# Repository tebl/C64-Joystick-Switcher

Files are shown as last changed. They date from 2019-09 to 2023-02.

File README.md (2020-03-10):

# C64 Joystick Switcher
I was watching [MsMadLemon](https://www.youtube.com/channel/UCSlMemxuBOFu6Rz_Al02nHQ) on [Youtube](https://youtu.be/DOF_CZoSF5g) the other day and she was making an autofire circuit, so naturally I wanted to build one too! Starting with the [C64 Mega Switcher](https://github.com/tebl/C64-Mega-Switcher) for the Commodore 64 (when you want to use Sega Genesis or Mega Drive Controllers instead), I stripped away some parts to clear space for the autofire parts, redesigned it a couple of times and then finally sketched out the whole thing again in order to figure out all the ways it didn't work. The last one thankfully worked, so now it's open and available for anyone with fingers they are willing to risk burning with a soldering iron (don't do that by the way, it hurts)!

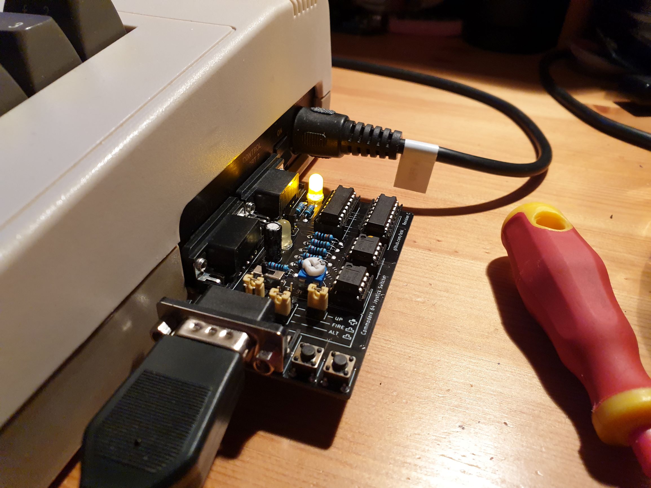
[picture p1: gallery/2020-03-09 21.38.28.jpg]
C64 Joystick Switcher


## Building the switcher
Soldering together the few components should be easy going as long as you have access to reasonable tools, personally I'm using a cheap soldering station with adjustable temperature so no need to go expensive if you don't have to. Use 60/40 soldering tin of reasonable quality, but stay away from the lead-free stuff unless you have experience working with it.

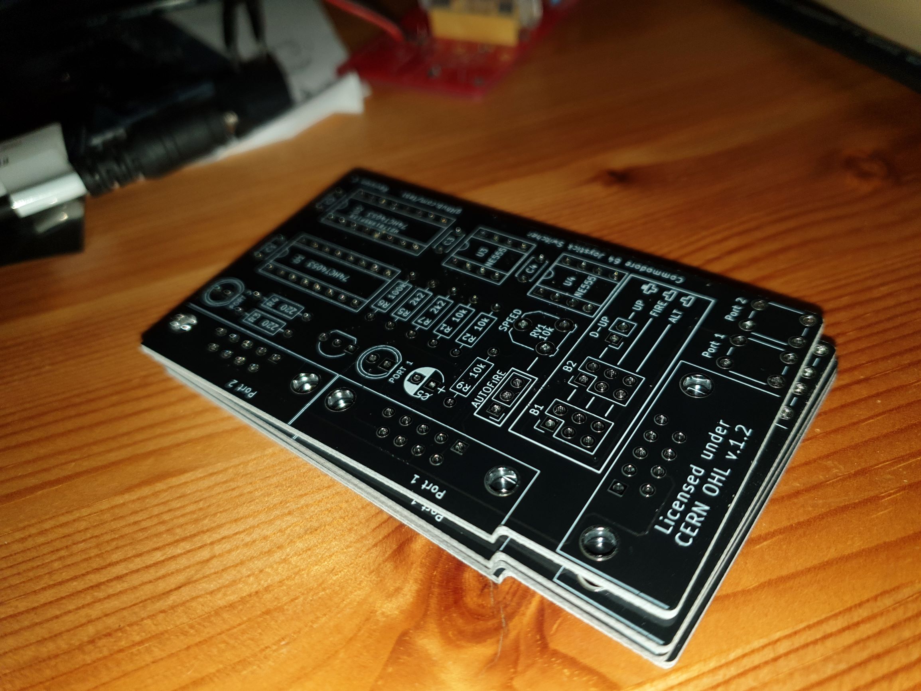
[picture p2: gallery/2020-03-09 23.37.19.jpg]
Bare PCB


Start by studying the PCB, both sides and perform dry fits to see that you have an idea of where everything goes since removing things is always a lot harder than getting it right in the first place (match orientation to symbols, see gallery images for reference if you're unsure). The diodes are installed standing, the stripe goes into the board so that it is laying directly against the board - a hint for making these look pretty, is wrapping one of the wires around a small screwdriver to get the loops looking almost identical!

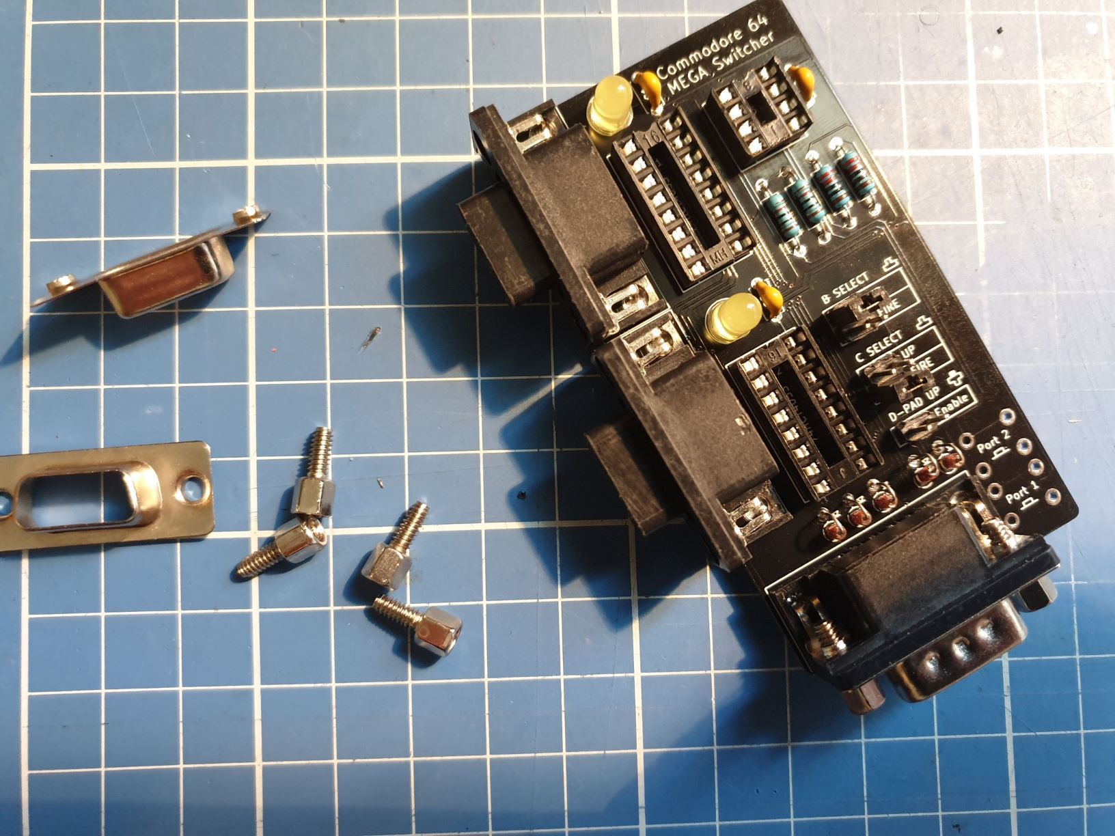
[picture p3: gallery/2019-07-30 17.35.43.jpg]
DB9 connector


The female DB9 connectors used for port 1/2 comes with a metal shroud, this comes off when you remove the two screws that would be in the way anyway (see image above for reference). Given that the C64 ports are made out of plastic, the metal shroud is not needed though you could possibly keep it by gluing it to the connector if you really wanted to, alternatively you could also fill the mounting holes with solder to keep them together afterwards. Do a testfit of the connectors with the C64 before soldering them to the board, this is recommended in order to avoid adding any stress to the C64 board.

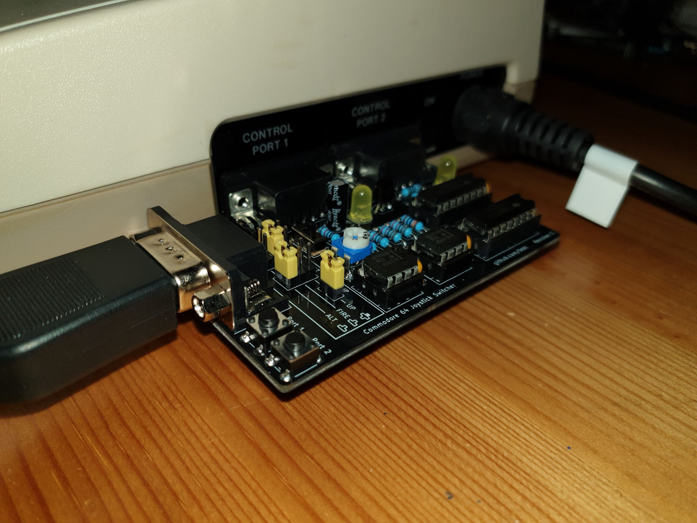
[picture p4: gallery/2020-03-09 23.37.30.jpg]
Connected to C64


Other than that, just take your time when doing the assembly - start by installing the smallest components first and then work your way up from there. Before actually plugging in anything into any antique computers, do a thorough visual inspection for any accidental solder-bridges. As a finishing note, I recommend putting something under the PCB to help support when pushing the buttons.

## Using the switcher
Firmly insert the switcher into the C64, making sure that it is inserted the whole way and fits firmly without feeling loose. When playing a game, if you encounter a game that expects a joystick inserted into the other port you can use the switches to change the currently active port.

**WARNING!**
 - Do **NOT** move any of the jumpers while the computer is switched on, doing so may cause damage to it. Always power off first!
 - Do **NOT** jumper so that more than one button/direction does the same thing, for example: if you jumper the B1 button for UP, then you have to REMOVE the jumper enabling D-PAD UP!
 - Do **NOT** use with actual Sega Genesis or Mega Drive controllers, if you want to use one of those - use [C64 Mega Switcher](https://github.com/tebl/C64-Mega-Switcher) instead.

You can use any common Atari-style joystick such as the Competition Pro and Zipstick, they are the ones I've tested with and currently also have in my collection. You can use the secondary fire button if you have one wired with this capability, most commonly the pinout is compatible with the Sega Master System gamepad. An auto-fire circuit has been added to the module, this can be handy if your controller does not include this functionality. 

# Schematic
The supplied KiCad files should be sufficient as both a schematic and as a  starting point for ordering PCBs (basically you could just zip the contents of the export folder and upload that on a fabrication site), the schematic is also available in [PDF-format](https://github.com/tebl/C64-Joystick-Switcher/raw/master/export/C64%20Joystick%20Switcher.pdf) and this is what you'll need to print and work your way through this things don't work as expected after assembly.

# BOM
Most parts should be easy to get a hold of from your favourite local electronic component shop, but given that I don't have access to such shops where I live so everything was based on whatever I could get cheapest from ebay/AliExpress (free shipping most places, but plan on waiting 3-4 weeks though). Pin headers are bought as strips with 40 pins, single or double rows, that you break into the specified sizes. Any amounts given in paranthesis are for optional functionality, mainly autofire and capability to utilize the secondary fire button if you have one. 

| Reference | Item | Count |
| --- | --- | ----- |
| PCB | Fabricate using Gerber files ([order](https://www.pcbway.com/project/shareproject/Commodore_64_Joystick_Switcher__Revision_C_.html?inviteid=88707)) | 1 |
| C1-C4 | 100nF capacitor | 4 |
| C5 | 10uF electrolytic capacitor | (1)|
| D1,D2 | 5mm LED | 2 |
| J1,J2 | Female DB9 right-angle connector | 2 |
| J3 | Male DB9 right-angle connector | 1 |
| J4,J5 | 2x3-pin straight header | 2 |
| JP2 | 3-pin straight header | 1 |
| Q1 | BC547 transistor (TO-92) | (1)|
| R1,R2 | 10k ohm resistor | 2 | 
| R3,R4 | 220 ohm resistor | 2 |
| R5,R7 | 2k2 (2200) ohm resistor | (2)|
| R6 | 100k ohm resistor | (1)|
| R9 | 10k ohm resistor | (1)| 
| RV1 | 10k ohm potentiometer (RM-065) | (1)| 
| U1,U2 | 74HCT4053 or CD4053 (DIP-16) | 2 |
| U3 | NE555 (DIP-8) | 1 |
| U4 | NE555 (DIP-8) | (1)|
| SW1,SW2 | SPST momentary push button | 2 |

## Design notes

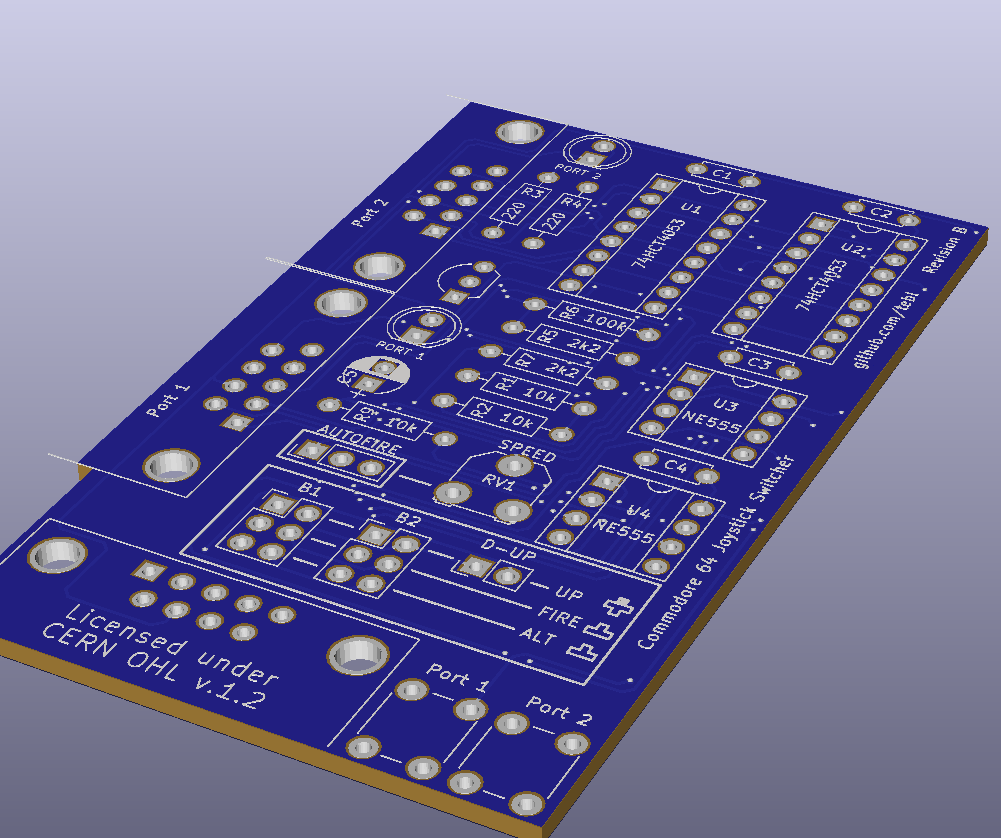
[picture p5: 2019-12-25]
gallery/C64 Joystick Switcher #2.png

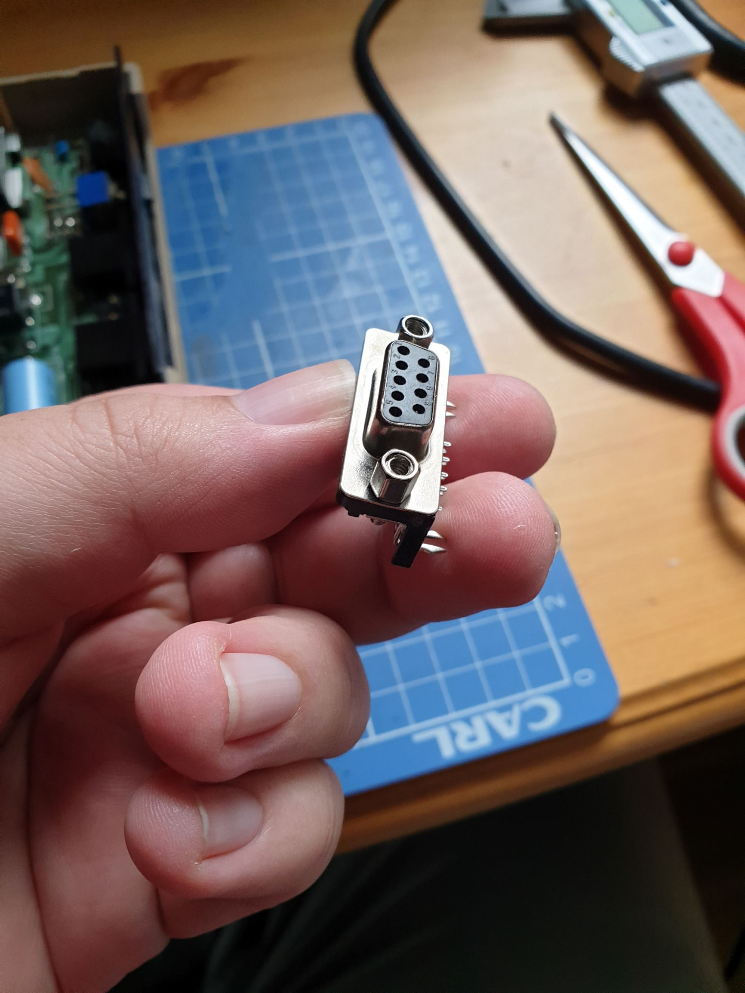
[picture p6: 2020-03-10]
gallery/2019-06-24 13.09.16.jpg

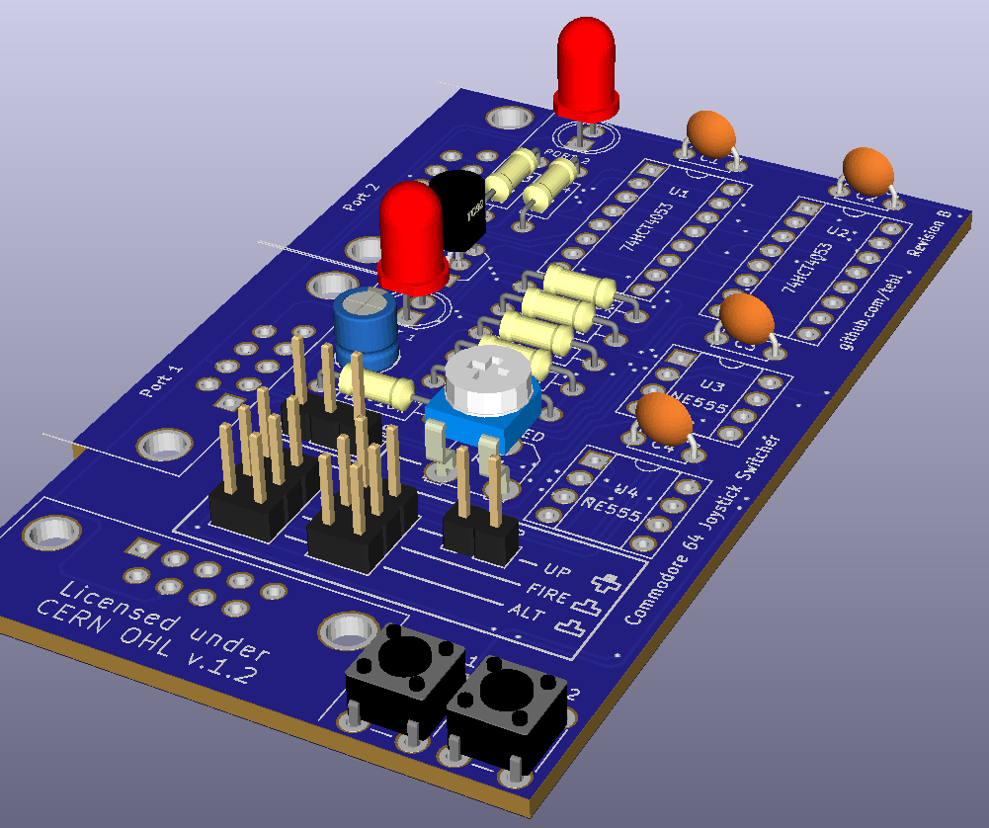
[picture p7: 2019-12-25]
gallery/C64 Joystick Switcher #1.png

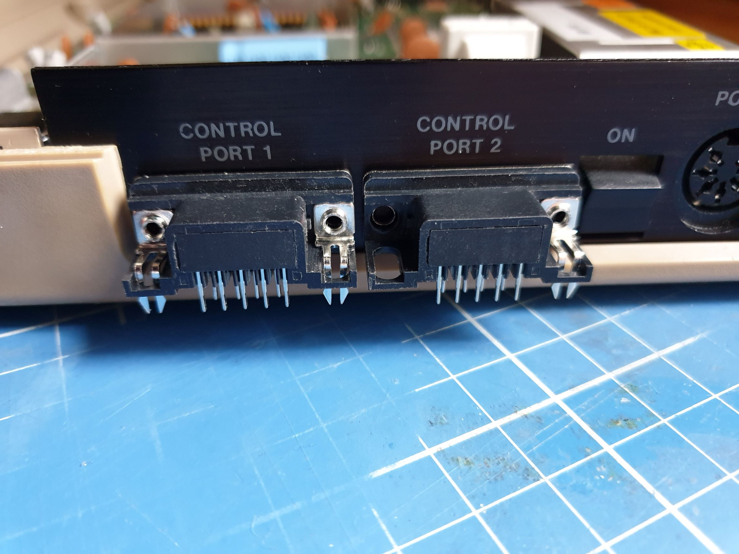
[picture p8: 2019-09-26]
gallery/2019-06-24 13.32.10.jpg

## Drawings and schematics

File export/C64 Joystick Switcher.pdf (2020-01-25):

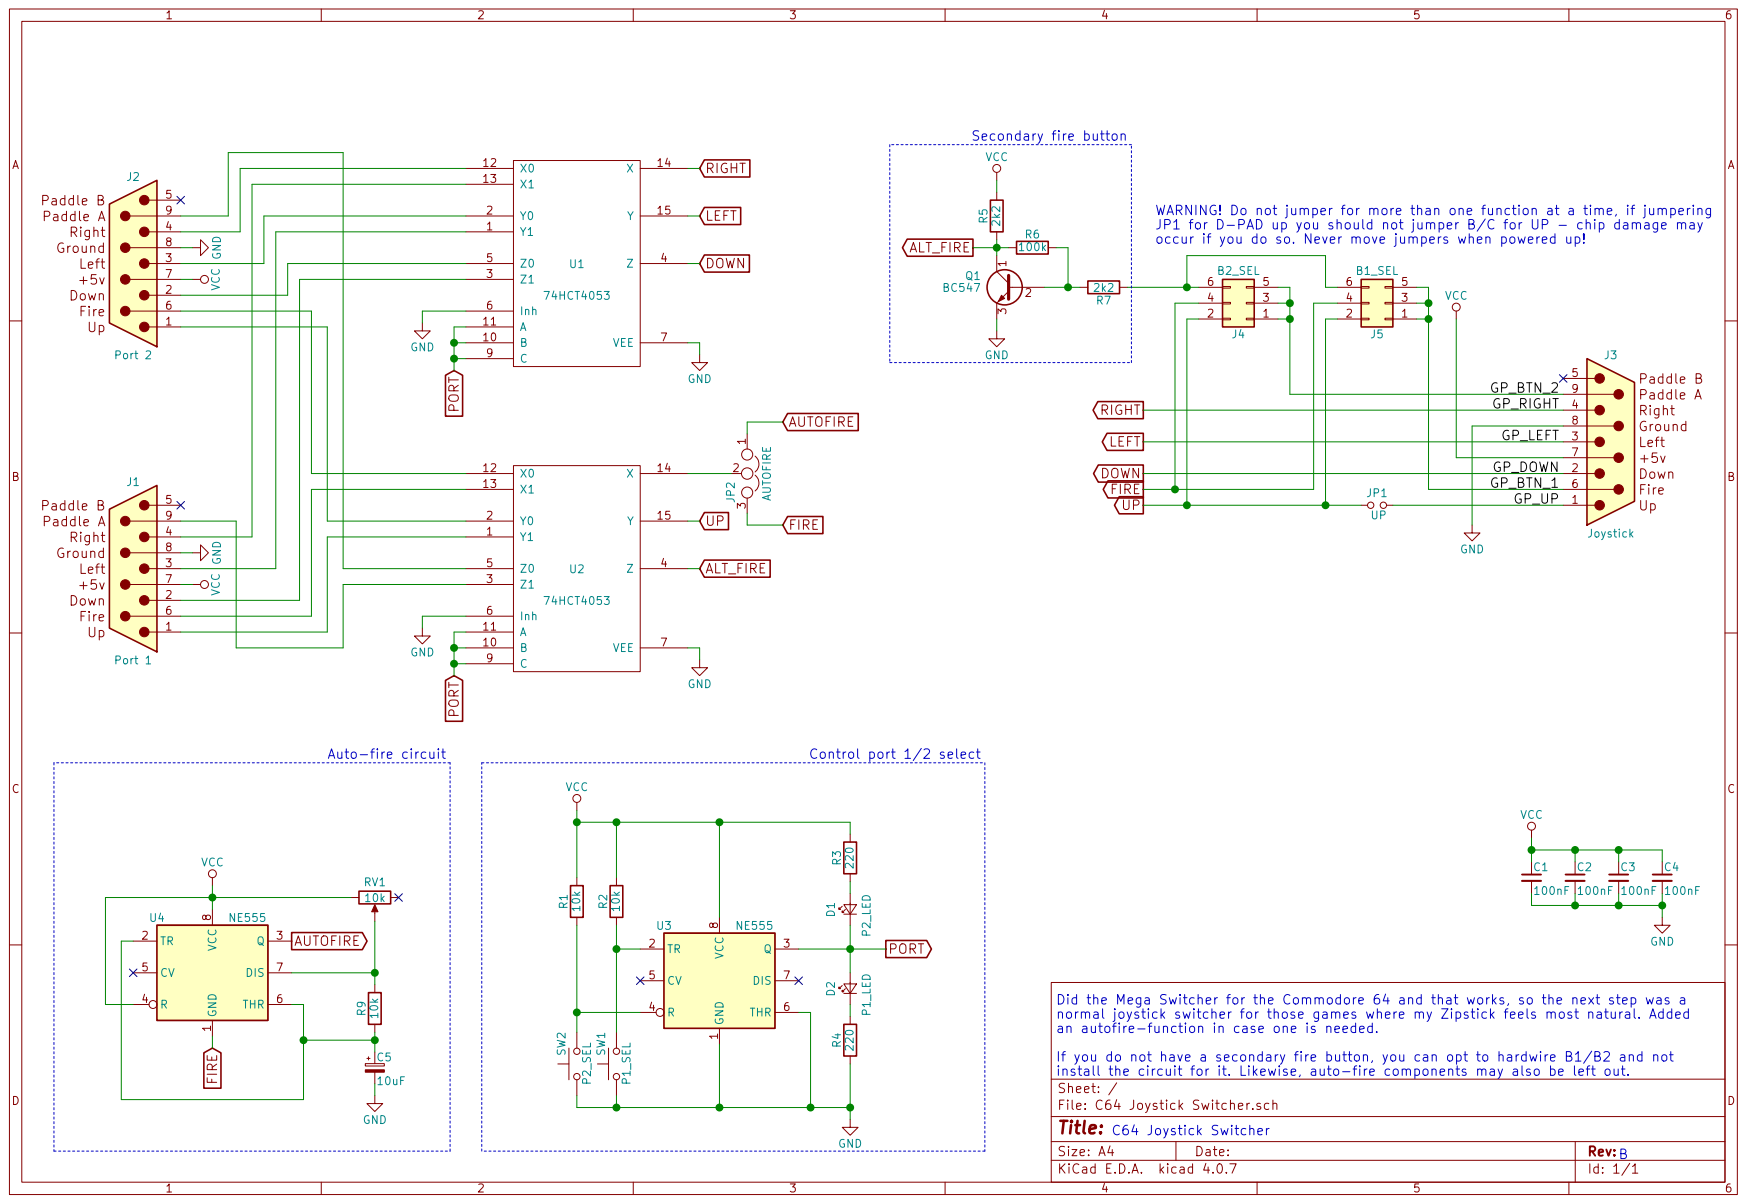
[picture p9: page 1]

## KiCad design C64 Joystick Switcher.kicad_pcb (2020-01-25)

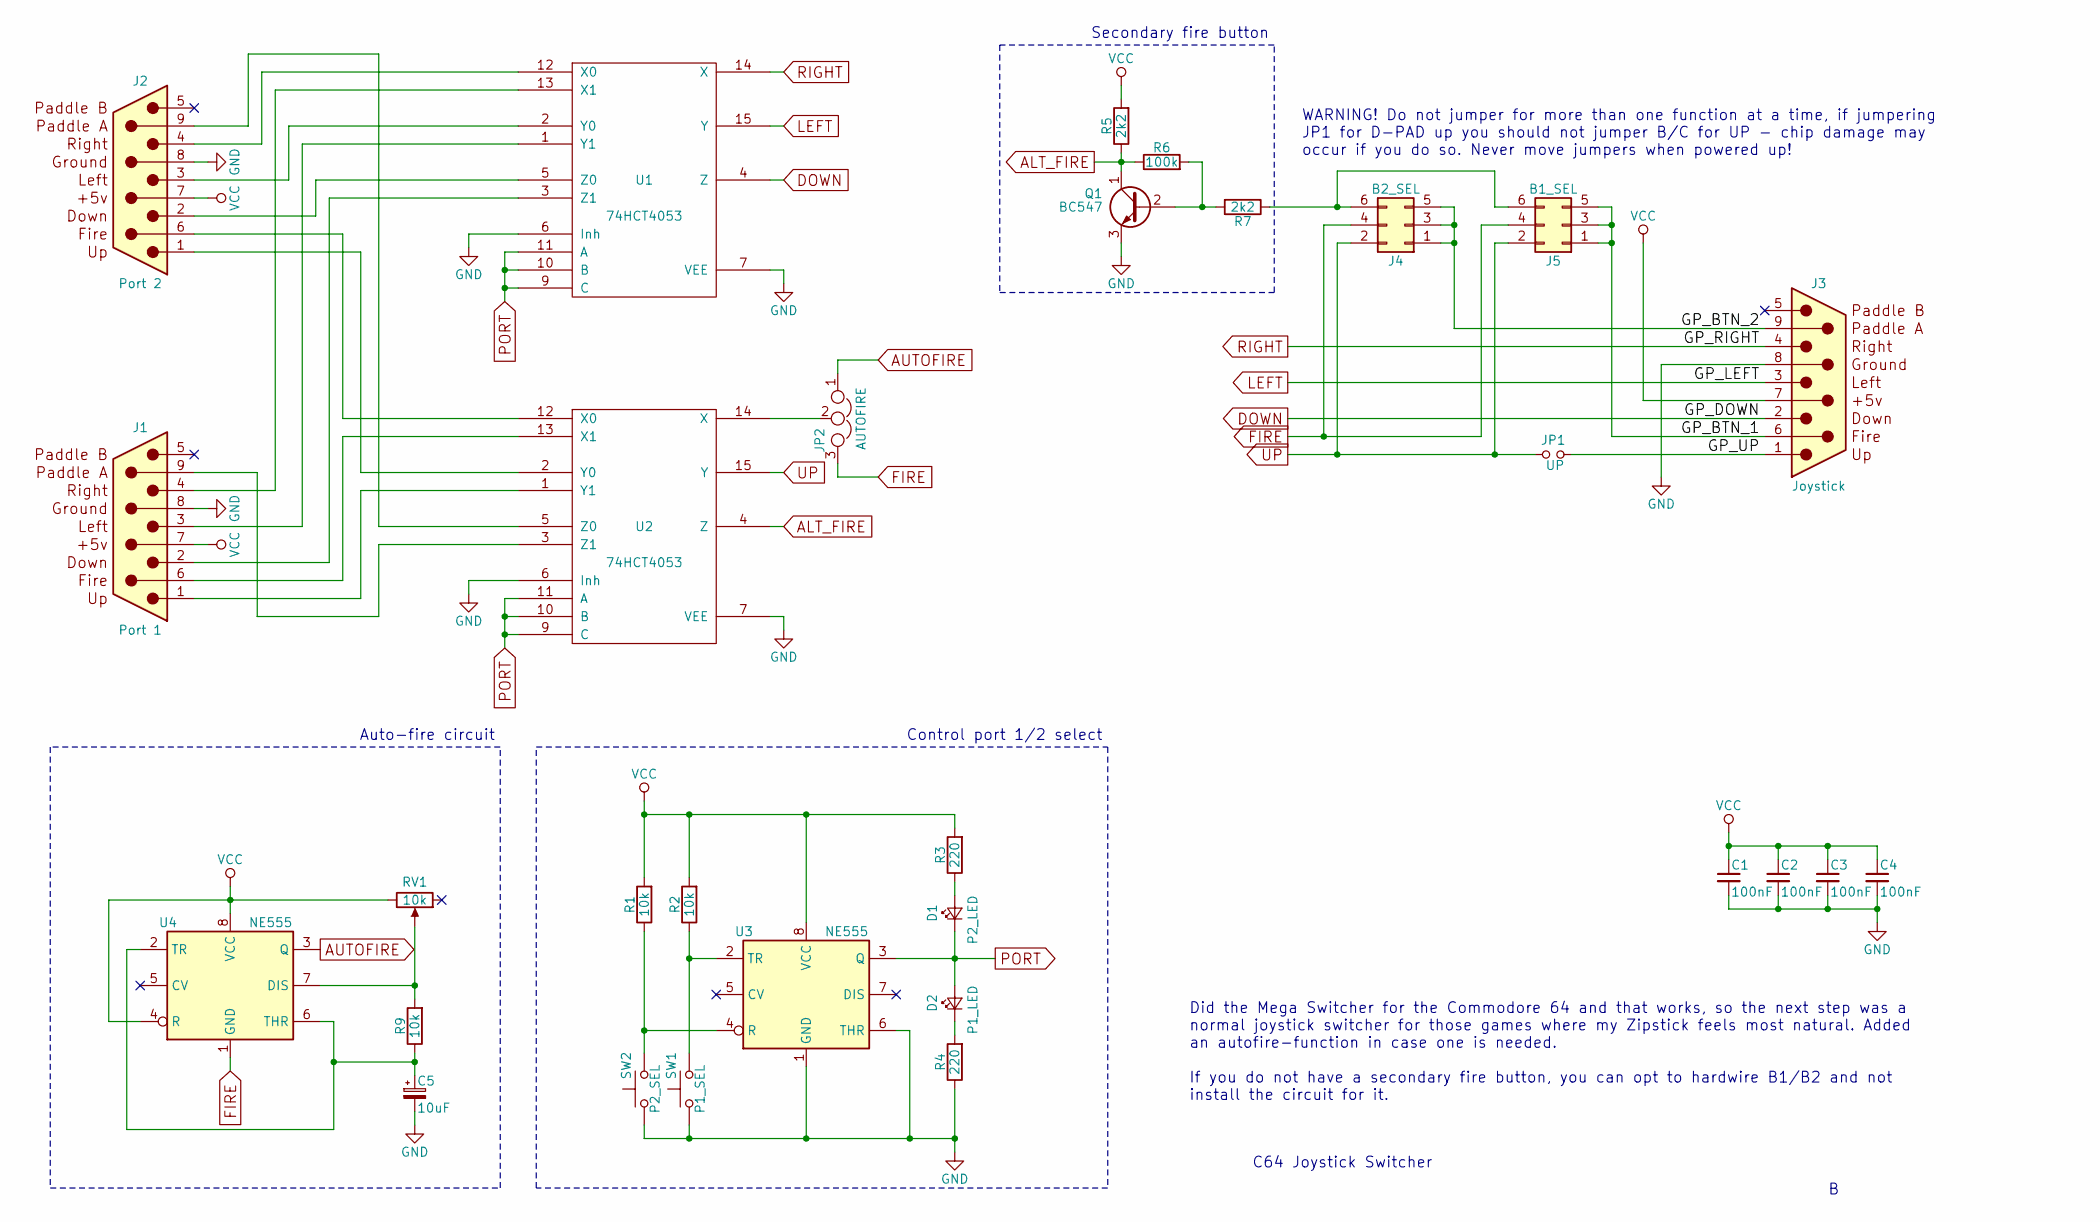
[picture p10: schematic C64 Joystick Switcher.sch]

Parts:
C1, C2, C3, C4: 100nF; C_Disc_D4.7mm_W2.5mm_P5.00mm
C5: 10uF; CP_Radial_D5.0mm_P2.50mm
D1: P2_LED; LED_D5.0mm
D2: P1_LED; LED_D5.0mm
J1: Port 1; DSUB-9_Female_Horizontal_P2.77x2.84mm_EdgePinOffset7.70mm_H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
J2: Port 2; DSUB-9_Female_Horizontal_P2.77x2.84mm_EdgePinOffset7.70mm_H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
J3: Joystick; DSUB-9_Male_Horizontal_P2.77x2.84mm_EdgePinOffset7.70mm_Hou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
J4: B2_SEL; Pin_Header_Straight_2x03_Pitch2.54mm
J5: B1_SEL; Pin_Header_Straight_2x03_Pitch2.54mm
JP1: UP; Pin_Header_Straight_1x02_Pitch2.54mm
JP2: AUTOFIRE; Pin_Header_Straight_1x03_Pitch2.54mm
Q1: BC547; TO-92_Inline_Wide
R1, R2, R9: 10k; R_Axial_DIN0207_L6.3mm_D2.5mm_P10.16mm_Horizontal
R3, R4: 220; R_Axial_DIN0207_L6.3mm_D2.5mm_P10.16mm_Horizontal
R5, R7: 2k2; R_Axial_DIN0207_L6.3mm_D2.5mm_P10.16mm_Horizontal
R6: 100k; R_Axial_DIN0207_L6.3mm_D2.5mm_P10.16mm_Horizontal
RV1: 10k; Potentiometer_Triwood_RM-065
SW1: P1_SEL; SW_PUSH_6mm
SW2: P2_SEL; SW_PUSH_6mm
U1, U2: 74HCT4053; DIP-16_W7.62mm_Socket
U3, U4: NE555; DIP-8_W7.62mm_Socket

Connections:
/GP_BTN_1: J3.6, J5.1, J5.3, J5.5
/GP_BTN_2: J3.9, J4.1, J4.3, J4.5
/GP_UP: J3.1, JP1.2
ALT_FIRE: Q1.1 (C), R5.1, R6.1, U2.4 (Z)
AUTOFIRE: JP2.1, U4.3 (Q)
DOWN: J3.2, U1.4 (Z)
FIRE: J4.4, J5.4, JP2.3, U4.1 (GND)
GND: C1.2, C2.2, C3.2, C4.2, C5.2, J1.8 (GND), J2.8 (GND), J3.8 (GND), Q1.3 (E), R4.1, SW1.1, SW2.1, U1.6 (Inh), U1.7 (VEE), U1.8 (GND), U2.6 (Inh), U2.7 (VEE), U2.8 (GND), U3.1 (GND), U3.6 (THR)
LEFT: J3.3, U1.15 (Y)
unnamed: C5.1, R9.1, U4.2 (TR), U4.6 (THR)
unnamed: D1.2 (A), R3.1
unnamed: D2.1 (K), R4.2
unnamed: J1.1, U2.1 (Y1)
unnamed: J1.2, U1.3 (Z1)
unnamed: J1.3, U1.1 (Y1)
unnamed: J1.4, U1.13 (X1)
unnamed: J1.6, U2.13 (X1)
unnamed: J1.9, U2.3 (Z1)
unnamed: J2.1, U2.2 (Y0)
unnamed: J2.2, U1.5 (Z0)
unnamed: J2.3, U1.2 (Y0)
unnamed: J2.4, U1.12 (X0)
unnamed: J2.6, U2.12 (X0)
unnamed: J2.9, U2.5 (Z0)
unnamed: J4.6, J5.6, R7.1
unnamed: JP2.2, U2.14 (X)
unnamed: Q1.2 (B), R6.2, R7.2
unnamed: R1.1, SW2.2, U3.4 (R)
unnamed: R2.1, SW1.2, U3.2 (TR)
unnamed: R9.2, RV1.2, U4.7 (DIS)
PORT: D1.1 (K), D2.2 (A), U1.9 (C), U1.10 (B), U1.11 (A), U2.9 (C), U2.10 (B), U2.11 (A), U3.3 (Q)
RIGHT: J3.4, U1.14 (X)
UP: J4.2, J5.2, JP1.1, U2.15 (Y)
VCC: C1.1, C2.1, C3.1, C4.1, J1.7 (VCC), J2.7 (VCC), J3.7 (VCC), R1.2, R2.2, R3.2, R5.2, RV1.3, U1.16 (VCC), U2.16 (VCC), U3.8 (VCC), U4.4 (R), U4.8 (VCC)

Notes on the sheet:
C64 Joystick Switcher
WARNING! Do not jumper for more than one function at a time, if jumpering JP1 for D-PAD up you should not jumper B/C for UP - chip damage may occur if you do so. Never move jumpers when powered up!
Did the Mega Switcher for the Commodore 64 and that works, so the next step was a normal joystick switcher for those games where my Zipstick feels most natural. Added an autofire-function in case one is needed. If you do not have a secondary fire button, you can opt to hardwire B1/B2 and not instal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
Auto-fire circuit
Control port 1/2 select
Secondary fire button

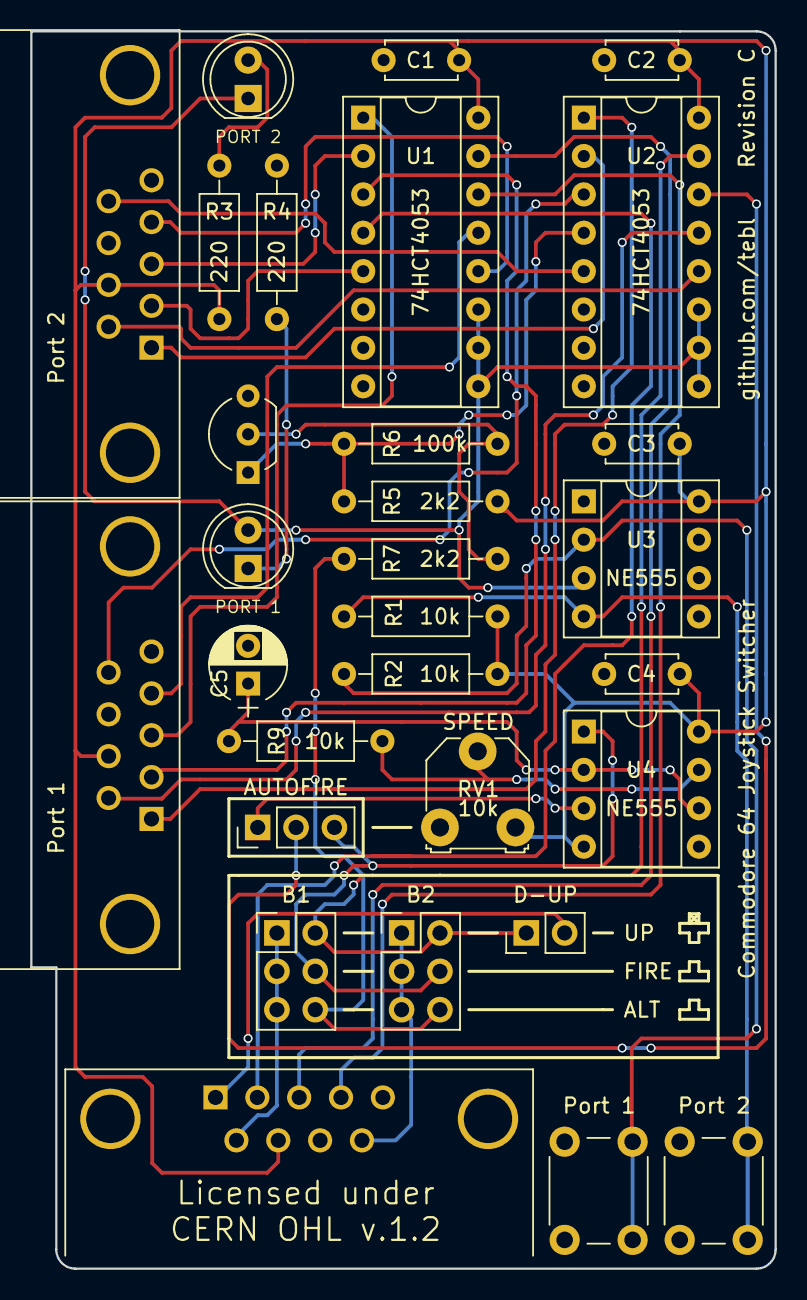
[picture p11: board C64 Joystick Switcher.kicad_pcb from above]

Board: 2 copper layers, 49.3 x 81.9 mm, 30 parts (0 on the bottom side), 34 nets.

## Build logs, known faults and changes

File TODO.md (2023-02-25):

# TODO
- Update project files to recent KiCAD
- Figure out a way to use port 1 fire button (SPACE on keyboard) when port 2 is selected.

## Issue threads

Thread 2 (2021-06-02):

Need Transistor?

NuClear235, 2021-06-02:
Hello,
Do I need transistor circuit, when I will use standard Atari Joystick with Button2 wired to pin9 of connector, please?
What function Transitor has? I dont want to use Sega controller anyway…
Thank You

tebl, 2021-06-03:
The C64 secondary button needs to be active high as it is connected to the
SiD chips analog input. The transistor as well as R5-R7 forms an inverter
for devices designed with an active low signal for this button (the most
common of these is the SMS gamepad).

When used with a C64GS controller that has already been wired correctly,
you can wire the circuit as expected by leaving out transistor as well as
R5-R7 - install wire links for R6 and R7.

Do however check the wiring on your joystick before doing so, the SID chip
don't like being shorted.

ons. 2. jun. 2021, 22:31 skrev NuClear235 ***@***.***>:

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

NuClear235, 2021-06-04:
Thank for answer.
I am using my own adapter, where is Button2 of Joy2 connected to Button1 of Joy1. So can have Fire2 button in games where is Button2 not supported, but is for action used SPACEBAR key.
Commando game throws grenades by SPACEBAR key. So I am using Button2 for it. This is  working only with selected joystick2 as main!
I will try improve  Your adapter to this function.
Best will be on B2SEL one more jumper possition /SPACEBAR/. Where will be signal connected to pin13.
Now I will just replace B2sel pin4 to harwired on fire13. I am just not sure what will do when will select main joystick 1 and press fire2 button with selected autofire. Will not be problem with grounding autofire out ?

NuClear235, 2021-06-07:
Hello,

Thank You for tips!

What do You mean on this message (see pic)?
What are jumpers B/C ?

Arent You on facebook or WhatsUp for just quick mesaging ?

Thank You

Michal Polak

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

tebl, 2021-06-07:
Jumpers B/C refer to the two 2x3 pin headers on the board, it is leftover
reference to an older similar project (uses Mega Drive/Genesis gamepads
instead). The are called B1_SEL and B2_SEL here, mainly allowing the
function of buttons to be swapped or have one work as up direction.

I rarely use the social platforms, for project discussion i prefer them on
github as the content may be of interest to other builders.

man. 7. jun. 2021, 07:54 skrev NuClear235 ***@***.***>:

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

NuClear235, 2021-06-07:
OK.

What could do, when I connecter Fire Button to UP without remove Jumper 1 ?

Isnt classic joystick just pasive switching signals to GND?

Michal

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

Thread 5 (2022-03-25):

Autofire not Working

fbugallo, 2022-03-25:
Hi, I can't get Auto Fire to work.

I am using PCBWAY revision C (https://www.pcbway.com/project/shareproject/Commodore_64_Joystick_Switcher__Revision_C_.html).

Assemble everything as indicated, and the other functionalities work perfectly.

I changed the 555 chip for a new one to see if it was the problem, I adjusted the preset and I didn't get any change at all, just no autofire.

What could it be? I can upload photos if you think necessary.

Thanks

fbugallo, 2022-03-26:
I changed the 555 for another brand and it worked fine. That same 555 worked ok for the port select function. I assume there is an incompatibility or it was a fake.

tebl, 2022-10-11:
Is JP2 set with pins 1-2 jumped? A broken RV1 would cause such an issue,
measure resistance across it to verify. Mounting the electrolytic the wrong
way around may cause similar issues. Then there's always the possibility of
a short somewhere.

See schematic for places that are expected to be linked and ones that are
not.

fre. 25. mar. 2022, 15:10 skrev fbugallo ***@***.***>:

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

Closed 2022-03-26.

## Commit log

2019-09-26 Drafted up first layout
    [C64 Joystick Switcher.kicad_pcb, C64 Joystick Switcher.sch]
2019-10-20 Gerber export
    [C64 Joystick Switcher-B.Cu.gbl, C64 Joystick Switcher-B.Mask.gbs, C64 Joystick Switcher-B.Paste.gbp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]
2019-12-25 Replace auto-fire circuit
    [C64 Joystick Switcher-B.Cu.gbl, C64 Joystick Switcher-B.Mask.gbs, C64 Joystick Switcher-B.Paste.gbp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]
2020-01-25 Auto-fire should now work
    [C64 Joystick Switcher-B.Cu.gbl, C64 Joystick Switcher-B.Mask.gbs, C64 Joystick Switcher-B.Paste.gbp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]
2020-01-25 Updated description
    [C64 Joystick Switcher.sch]
2020-03-10 Update pcbway url

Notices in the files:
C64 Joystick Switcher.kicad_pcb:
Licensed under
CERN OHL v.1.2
